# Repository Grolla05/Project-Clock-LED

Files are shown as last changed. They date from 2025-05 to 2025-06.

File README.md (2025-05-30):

# ⏱️ Project Clock LED — Digital Clock with Logic Circuits

> A fully functional digital clock built **without programming**, using only digital logic and discrete electronics.



---

## 🧩 What is DigitalClock?

**DigitalClock** is a project developed with the goal of creating a **complete digital clock** capable of accurately counting hours, minutes, and seconds using **only discrete electronic components and digital logic circuits**, **without any programming languages or microcontrollers**.

The project was designed to practically apply knowledge acquired in **Electronics** and **Digital Circuits** courses, resulting in a system capable of operating continuously and stably, displaying the time in real-time on **seven-segment LED displays**.

---

## 🎯 Project Objectives

- ⚡ Design and implement a **rectifier power supply** with proper filtering to power the digital circuits  
- ⏳ Develop a **clock generation system** using **delay and frequency divider circuits**  
- 🔁 Create **synchronous and asynchronous counters** using D flip-flops to count seconds, minutes, and hours  
- 🔢 Integrate **binary to 7-segment decoders** with the counters to correctly display the time values  

---

## ⚙️ Features

✔️ Accurate time counting (hours, minutes, and seconds)  
✔️ Continuous and stable real-time operation  
✔️ Real-time updates on seven-segment displays  
✔️ Fully built with discrete digital logic components  
✔️ No programming or microcontrollers involved  
✔️ Educational project focused on fundamental electronics

---

## 🛠️ Components and Technologies

- **D-type Flip-Flops**  
- **Synchronous/Asynchronous Counters**
- **Pulse Generator (CLOCK)** 
- **Frequency Dividers**  
- **BCD to 7-Segment Decoders**  
- **7-Segment LED Displays**
- **Diode LED's**
- **Rectifier Power Supply with Filter Capacitors**  
- **Logic Gates (AND, NOT, etc...)**

---

## ✨ System Demonstration

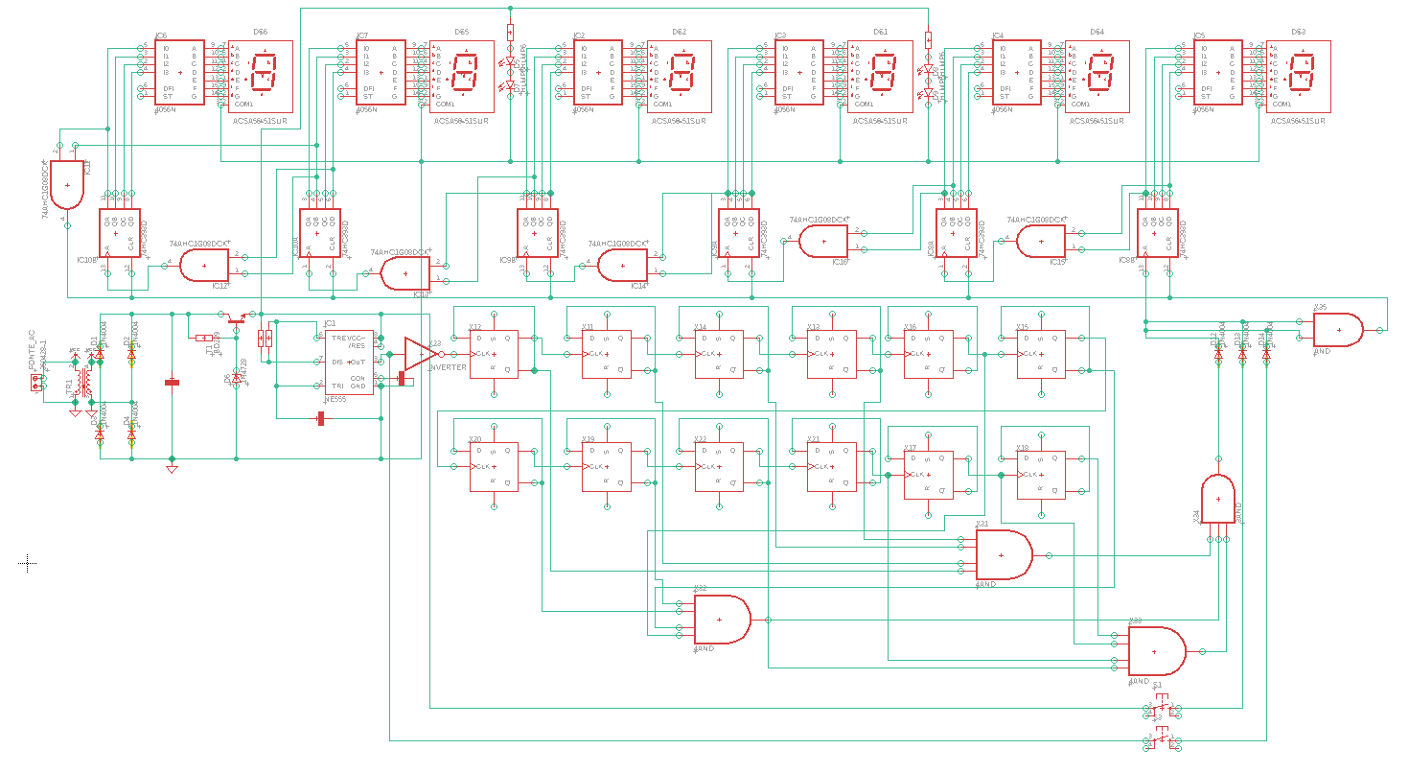
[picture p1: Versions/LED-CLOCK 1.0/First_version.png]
 <br>
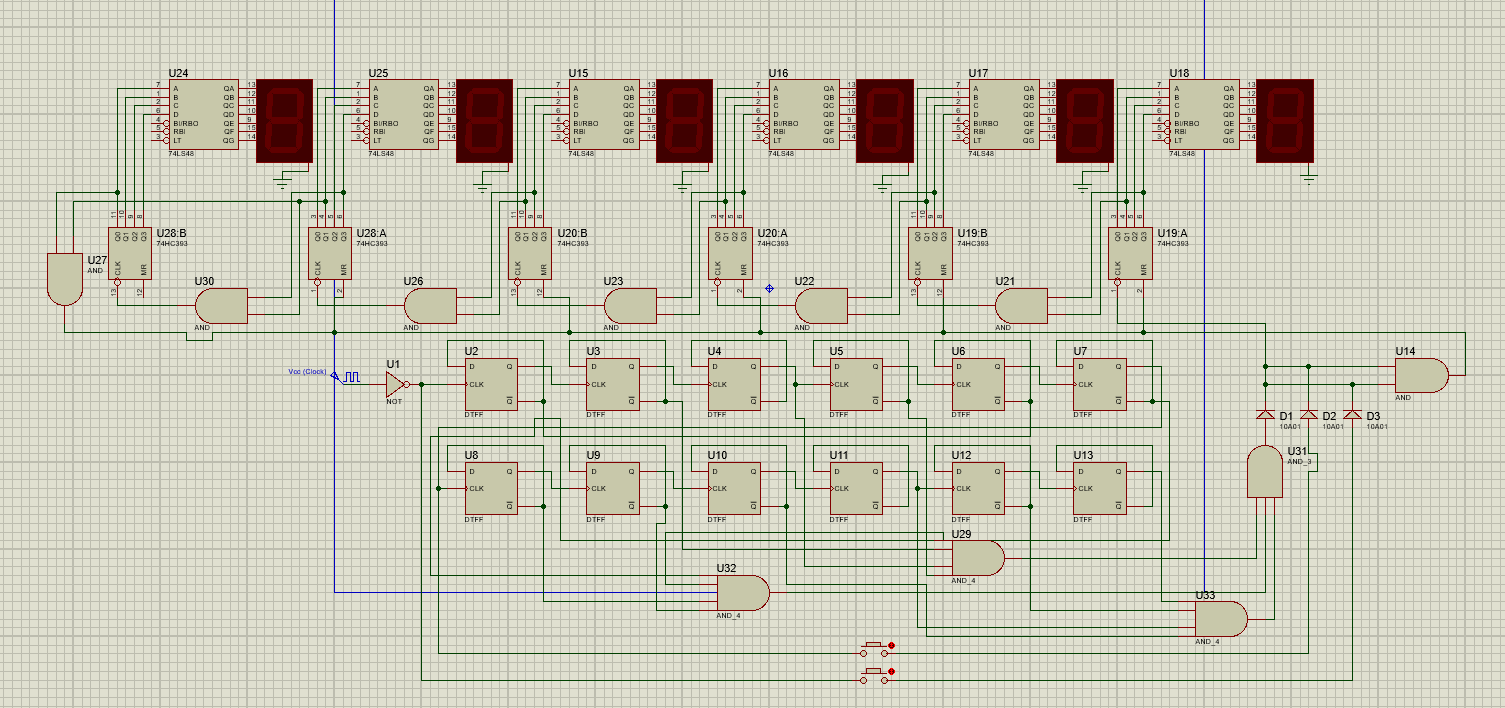
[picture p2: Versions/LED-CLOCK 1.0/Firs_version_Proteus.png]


---

## 👥 Author's

Developed by:

- **Felipe Grolla Freitas** – Control and Automation Engineering Student (PUC-Campinas)
- **Guilherme Oliveira Nogueira** - Control and Automation Engineering Student (PUC-Campinas)
- **Giovanna Lima Salvagnini** - Control and Automation Engineering Student (PUC-Campinas)
- **Henrique Spadaccia Chambó** - Control and Automation Engineering Student (PUC-Campinas)

---

## 💬 Contributions and Learning

This project demonstrated how to build a fully functional digital system using only the fundamentals of sequential and combinational logic.  
It reinforced practical understanding of counters, timing, clock generation, and display interfacing without any programming.

---

> 🧠 *"Digital logic can build time — one pulse at a time."*

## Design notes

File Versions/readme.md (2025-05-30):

# Materials list

- **6 - 7 seg display**
- **6 - decodificador (7 segmentos display)**
- **6 - registradores de 4 bits**
- **4 - leds simples**
- **7 - Portas ands simples**
- **1 - porta and de 3 entradas**
- **3 - porta and de 4 entradas**
- **2 - botões (chave)**
- **12 - flipflops tipo D**
- **1 - porta not**
- **7 - diodos retificadores**
- **1 - oscilador NE555**
- **1 - resistor 1K**
- **1 - transistor NPN BD135**
- **1 - capacitor 220 uF**
- **1 - Zener 1N4728**
- **1 - transformador de 127v para 6v**

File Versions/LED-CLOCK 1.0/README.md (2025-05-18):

## First version of the project (CLOCK LED with only analog and logic circuit)



## First version of the project in proteus



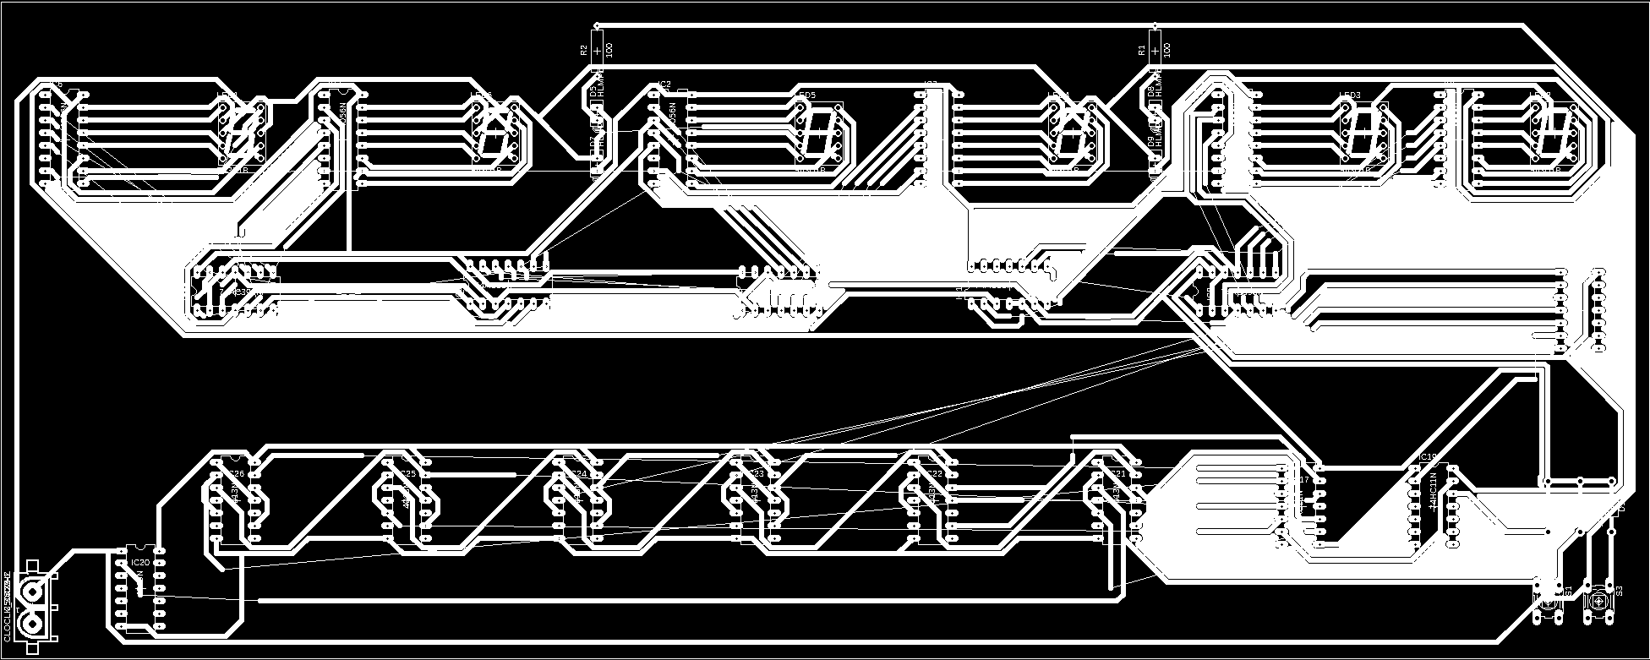
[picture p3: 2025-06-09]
Versions/LED-CLOCK 1.0/Modulo 1/Bottom side 2.png

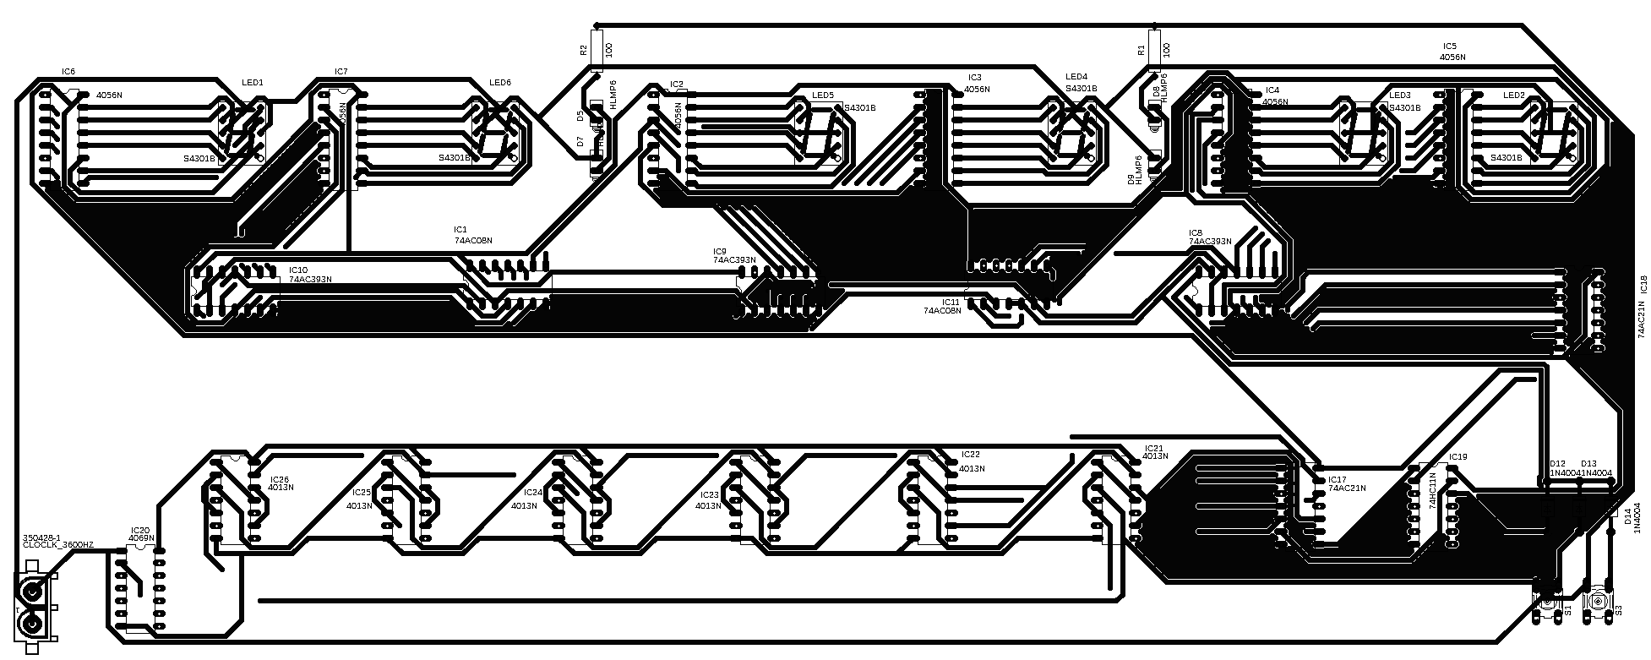
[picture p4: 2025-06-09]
Versions/LED-CLOCK 1.0/Modulo 1/Bottom side.png

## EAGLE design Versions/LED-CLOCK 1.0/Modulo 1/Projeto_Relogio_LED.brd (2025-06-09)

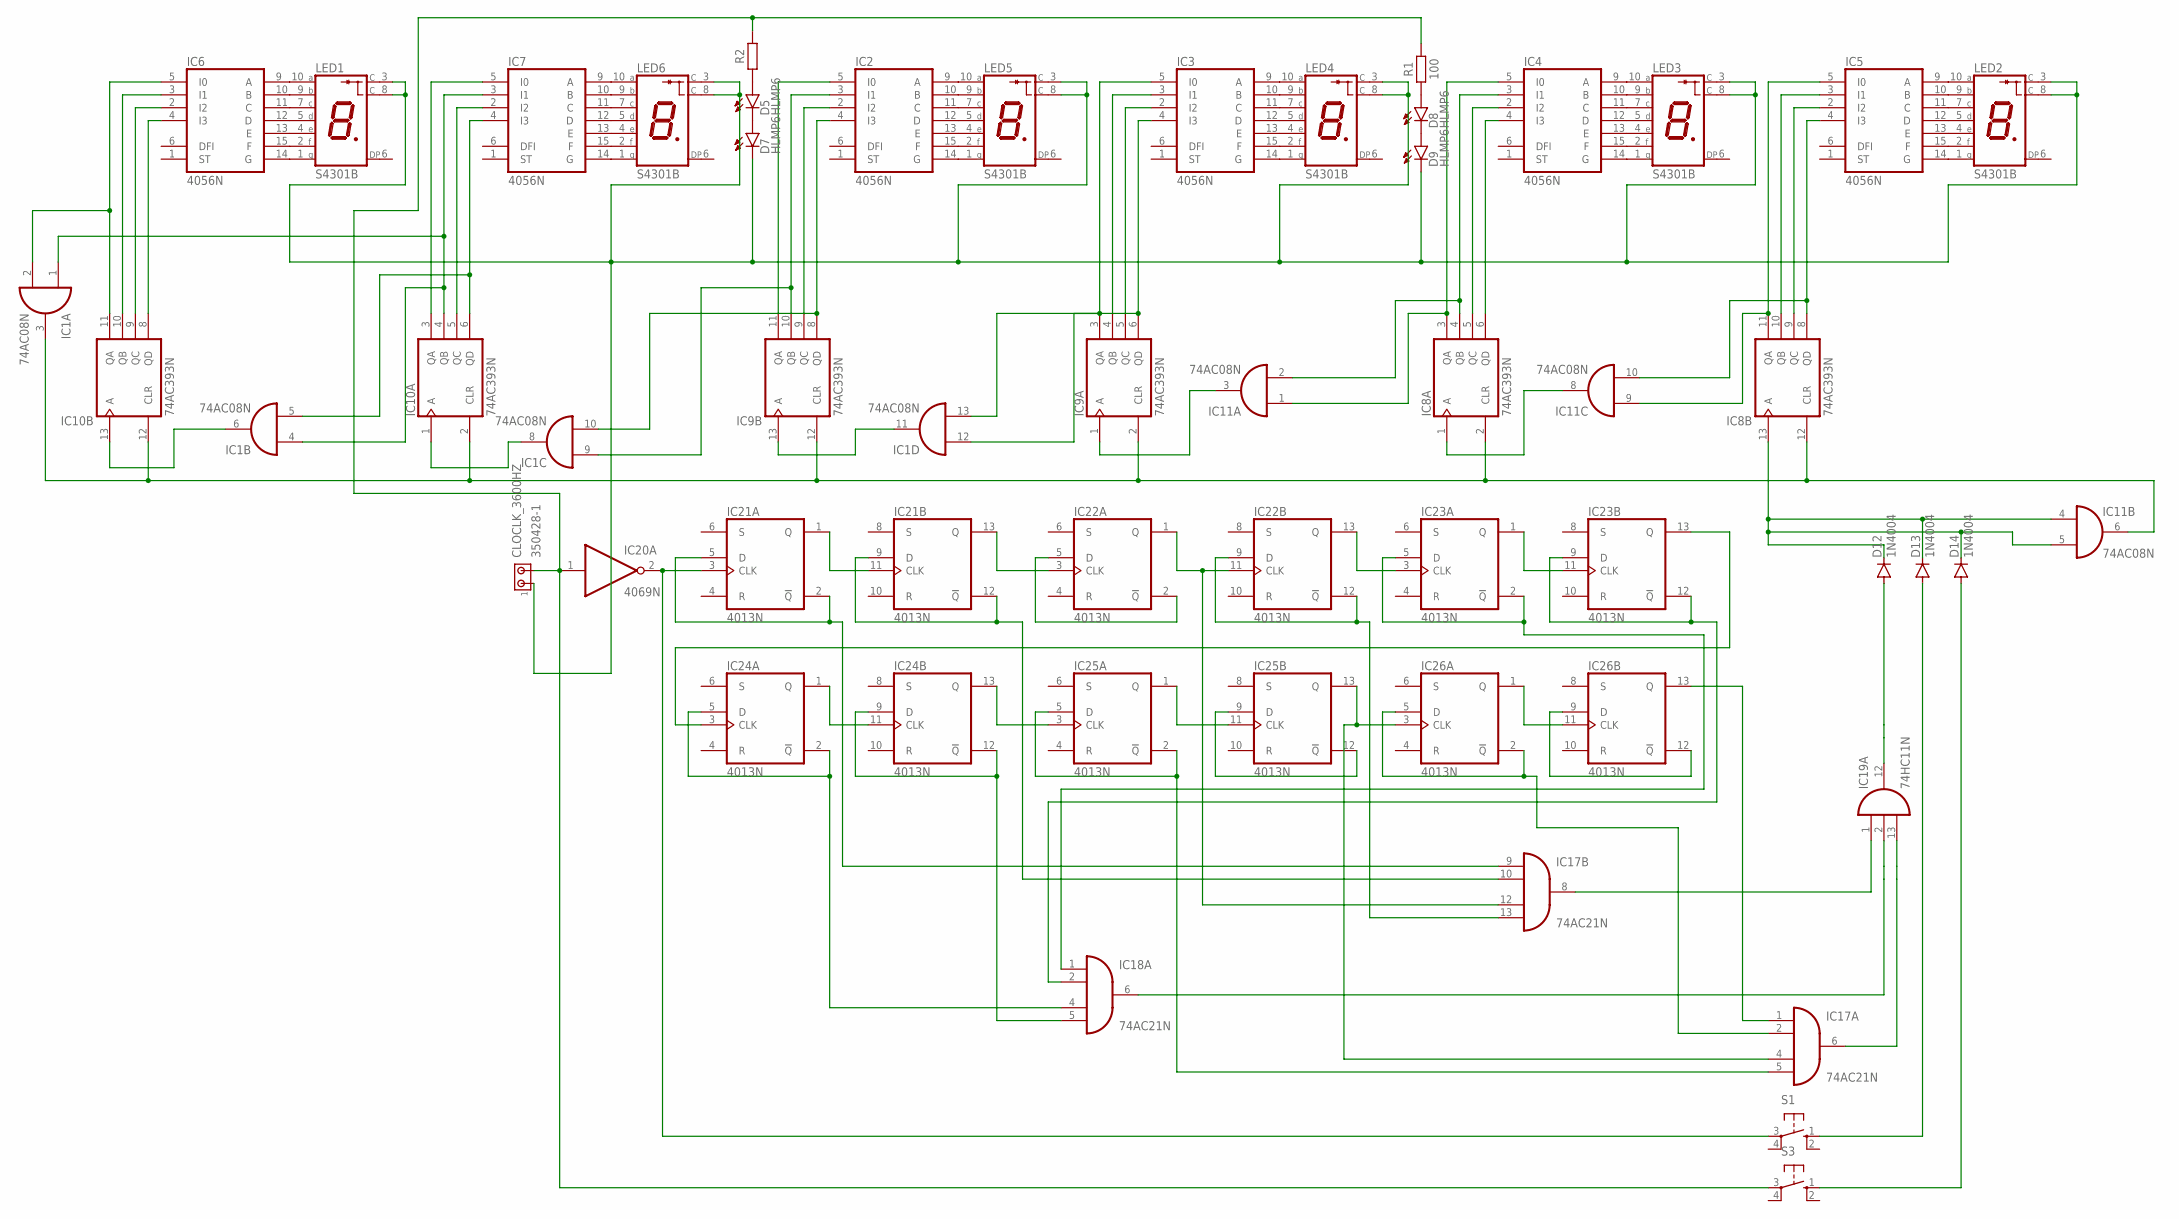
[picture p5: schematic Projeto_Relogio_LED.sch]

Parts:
CLOCLK_3600HZ: 350428-1
D5, D7, D8, D9: HLMP6
D12, D13, D14: 1N4004; DO41-10
IC1, IC11: 74AC08N; DIL14
IC2, IC3, IC4, IC5, IC6, IC7: 4056N; DIL16
IC8, IC9, IC10: 74AC393N; DIL14
IC17, IC18: 74AC21N; DIL14
IC19: 74HC11N; DIL14
IC20: 4069N; DIL14
IC21, IC22, IC23, IC24, IC25, IC26: 4013N; DIL14
LED1, LED2, LED3, LED4, LED5, LED6: S4301B
R1, R2: 100; RESAD1016W63L850D250B
S1, S3: 10-XX; B3F-10XX

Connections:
GND: IC1.7 (GND), IC2.8 (GND), IC3.8 (GND), IC4.8 (GND), IC5.8 (GND), IC6.8 (GND), IC7.8 (GND), IC8.7 (GND), IC9.7 (GND), IC10.7 (GND), IC11.7 (GND), IC17.7 (GND), IC18.7 (GND), IC19.7 (GND)
unnamed: IC1.8 (O), IC10.1 (A)
unnamed: IC5.4 (I3), IC8.8 (QD), IC11.10 (I1)
unnamed: IC8.1 (A), IC11.8 (O)
unnamed: D5.A, R2.1
unnamed: D8.A, R1.1
unnamed: D12.A, IC19.12 (O)
unnamed: IC20.2 (O), IC21.3 (CLK), S1.3
unnamed: IC21.1 (Q), IC21.11 (CLK)
unnamed: CLOCLK_3600HZ.2, IC20.1 (I), R1.2, R2.2, S3.3
unnamed: IC21.13 (Q), IC22.3 (CLK)
unnamed: IC17.12 (I2), IC22.1 (Q), IC22.11 (CLK)
unnamed: IC22.13 (Q), IC23.3 (CLK)
unnamed: IC23.1 (Q), IC23.11 (CLK)
unnamed: IC24.1 (Q), IC24.11 (CLK)
unnamed: IC18.4 (I2), IC24.2 (!Q), IC24.5 (D)
unnamed: IC24.13 (Q), IC25.3 (CLK)
unnamed: IC25.1 (Q), IC25.11 (CLK)
unnamed: IC17.4 (I2), IC25.13 (Q), IC26.3 (CLK)
unnamed: IC26.1 (Q), IC26.11 (CLK)
unnamed: IC23.13 (Q), IC24.3 (CLK)
unnamed: IC7.14 (G), LED6.1 (G)
unnamed: IC7.15 (F), LED6.2 (F)
unnamed: IC7.13 (E), LED6.4 (E)
unnamed: IC7.12 (D), LED6.5 (D)
unnamed: IC7.11 (C), LED6.7 (C)
unnamed: IC7.10 (B), LED6.9 (B)
unnamed: IC7.9 (A), LED6.10 (A)
unnamed: IC6.9 (A), LED1.10 (A)
unnamed: IC6.10 (B), LED1.9 (B)
unnamed: IC6.11 (C), LED1.7 (C)
unnamed: IC6.12 (D), LED1.5 (D)
unnamed: IC6.13 (E), LED1.4 (E)
unnamed: IC6.15 (F), LED1.2 (F)
unnamed: IC6.14 (G), LED1.1 (G)
unnamed: IC2.14 (G), LED5.1 (G)
unnamed: IC2.15 (F), LED5.2 (F)
unnamed: IC2.13 (E), LED5.4 (E)
unnamed: IC2.12 (D), LED5.5 (D)
unnamed: IC2.11 (C), LED5.7 (C)
unnamed: IC2.10 (B), LED5.9 (B)
unnamed: IC2.9 (A), LED5.10 (A)
unnamed: IC3.9 (A), LED4.10 (A)
unnamed: IC3.10 (B), LED4.9 (B)
unnamed: IC3.11 (C), LED4.7 (C)
unnamed: IC3.12 (D), LED4.5 (D)
unnamed: IC3.13 (E), LED4.4 (E)
unnamed: IC3.15 (F), LED4.2 (F)
unnamed: IC3.14 (G), LED4.1 (G)
unnamed: IC4.14 (G), LED3.1 (G)
unnamed: IC4.15 (F), LED3.2 (F)
unnamed: IC4.13 (E), LED3.4 (E)
unnamed: IC4.12 (D), LED3.5 (D)
unnamed: IC4.11 (C), LED3.7 (C)
unnamed: IC4.10 (B), LED3.9 (B)
unnamed: IC4.9 (A), LED3.10 (A)
unnamed: IC5.14 (G), LED2.1 (G)
unnamed: IC5.15 (F), LED2.2 (F)
unnamed: IC5.13 (E), LED2.4 (E)
unnamed: IC5.12 (D), LED2.5 (D)
unnamed: IC5.11 (C), LED2.7 (C)
unnamed: IC5.10 (B), LED2.9 (B)
unnamed: IC5.9 (A), LED2.10 (A)
unnamed: IC4.4 (I3), IC8.6 (QD)
unnamed: IC4.2 (I2), IC8.5 (QC)
unnamed: IC4.3 (I1), IC8.4 (QB), IC11.2 (I1)
unnamed: IC4.5 (I0), IC8.3 (QA), IC11.1 (I0)
unnamed: IC5.2 (I2), IC8.9 (QC)
unnamed: IC5.3 (I1), IC8.10 (QB)
unnamed: IC5.5 (I0), IC8.11 (QA), IC11.9 (I0)
unnamed: IC1.13 (I1), IC3.4 (I3), IC9.6 (QD)
unnamed: IC3.2 (I2), IC9.5 (QC)
unnamed: IC3.3 (I1), IC9.4 (QB)
unnamed: IC1.12 (I0), IC3.5 (I0), IC9.3 (QA)
unnamed: IC1.10 (I1), IC2.4 (I3), IC9.8 (QD)
unnamed: IC2.2 (I2), IC9.9 (QC)
unnamed: IC1.9 (I0), IC2.3 (I1), IC9.10 (QB)
unnamed: IC2.5 (I0), IC9.11 (QA)
unnamed: IC1.5 (I1), IC7.4 (I3), IC10.6 (QD)
unnamed: IC7.2 (I2), IC10.5 (QC)
unnamed: IC1.1 (I0), IC1.4 (I0), IC7.3 (I1), IC10.4 (QB)
unnamed: IC7.5 (I0), IC10.3 (QA)
unnamed: IC6.4 (I3), IC10.8 (QD)
unnamed: IC6.2 (I2), IC10.9 (QC)
unnamed: IC6.3 (I1), IC10.10 (QB)
unnamed: IC1.2 (I1), IC6.5 (I0), IC10.11 (QA)
unnamed: D5.K, D7.A
unnamed: D8.K, D9.A
unnamed: IC17.10 (I1), IC21.9 (D), IC21.12 (!Q)
unnamed: IC22.2 (!Q), IC22.5 (D)
unnamed: IC17.13 (I3), IC22.9 (D), IC22.12 (!Q)
unnamed: IC1.6 (O), IC10.13 (A)
unnamed: IC18.1 (I0), IC23.2 (!Q), IC23.5 (D)
unnamed: IC18.2 (I1), IC23.9 (D), IC23.12 (!Q)
unnamed: IC18.5 (I3), IC24.9 (D), IC24.12 (!Q)
unnamed: IC17.5 (I3), IC25.2 (!Q), IC25.5 (D)
unnamed: IC25.9 (D), IC25.12 (!Q)
unnamed: IC26.9 (D), IC26.12 (!Q)
unnamed: IC17.9 (I0), IC21.2 (!Q), IC21.5 (D)
unnamed: D12.C, D13.C, D14.C, IC8.13 (A), IC11.4 (I0), IC11.5 (I1)
unnamed: IC17.8 (O), IC19.1 (I0)
unnamed: D13.A, S1.1 (S)
unnamed: D14.A, S3.1 (S)
unnamed: IC18.6 (O), IC19.2 (I1)
unnamed: IC1.3 (O), IC8.2 (CLR), IC8.12 (CLR), IC9.2 (CLR), IC9.12 (CLR), IC10.2 (CLR), IC10.12 (CLR), IC11.6 (O)
unnamed: IC17.1 (I0), IC26.13 (Q)
unnamed: CLOCLK_3600HZ.1, D7.K, D9.K, LED1.3 (C), LED1.8 (C), LED2.3 (C), LED2.8 (C), LED3.3 (C), LED3.8 (C), LED4.3 (C), LED4.8 (C), LED5.3 (C), LED5.8 (C), LED6.3 (C), LED6.8 (C)
unnamed: IC9.1 (A), IC11.3 (O)
unnamed: IC17.2 (I1), IC26.2 (!Q), IC26.5 (D)
unnamed: IC1.11 (O), IC9.13 (A)
unnamed: IC17.6 (O), IC19.13 (I2)
VCC: IC1.14 (VCC), IC2.16 (VCC), IC3.16 (VCC), IC4.16 (VCC), IC5.16 (VCC), IC6.16 (VCC), IC7.16 (VCC), IC8.14 (VCC), IC9.14 (VCC), IC10.14 (VCC), IC11.14 (VCC), IC17.14 (VCC), IC18.14 (VCC), IC19.14 (VCC)
VDD: IC20.14 (VDD), IC21.14 (VDD), IC22.14 (VDD), IC23.14 (VDD), IC24.14 (VDD), IC25.14 (VDD), IC26.14 (VDD)
VEE: IC2.7 (VEE), IC3.7 (VEE), IC4.7 (VEE), IC5.7 (VEE), IC6.7 (VEE), IC7.7 (VEE)
VSS: IC20.7 (VSS), IC21.7 (VSS), IC22.7 (VSS), IC23.7 (VSS), IC24.7 (VSS), IC25.7 (VSS), IC26.7 (VSS)

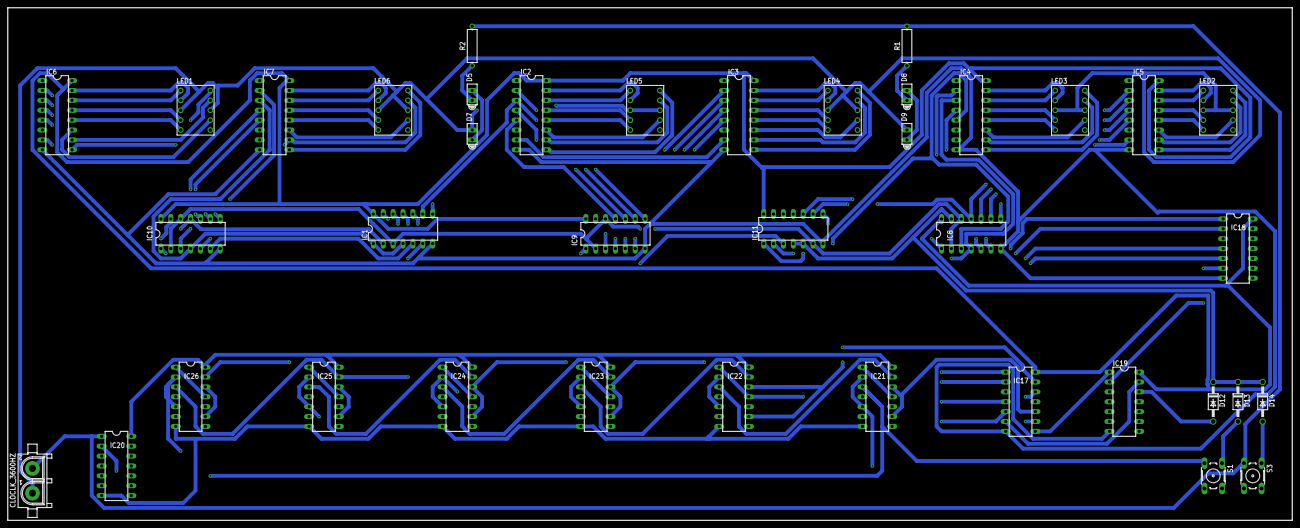
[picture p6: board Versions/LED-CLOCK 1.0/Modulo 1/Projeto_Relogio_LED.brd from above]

Board: 2 copper layers, 330.2 x 131.8 mm, 39 parts (0 on the bottom side), 115 nets.

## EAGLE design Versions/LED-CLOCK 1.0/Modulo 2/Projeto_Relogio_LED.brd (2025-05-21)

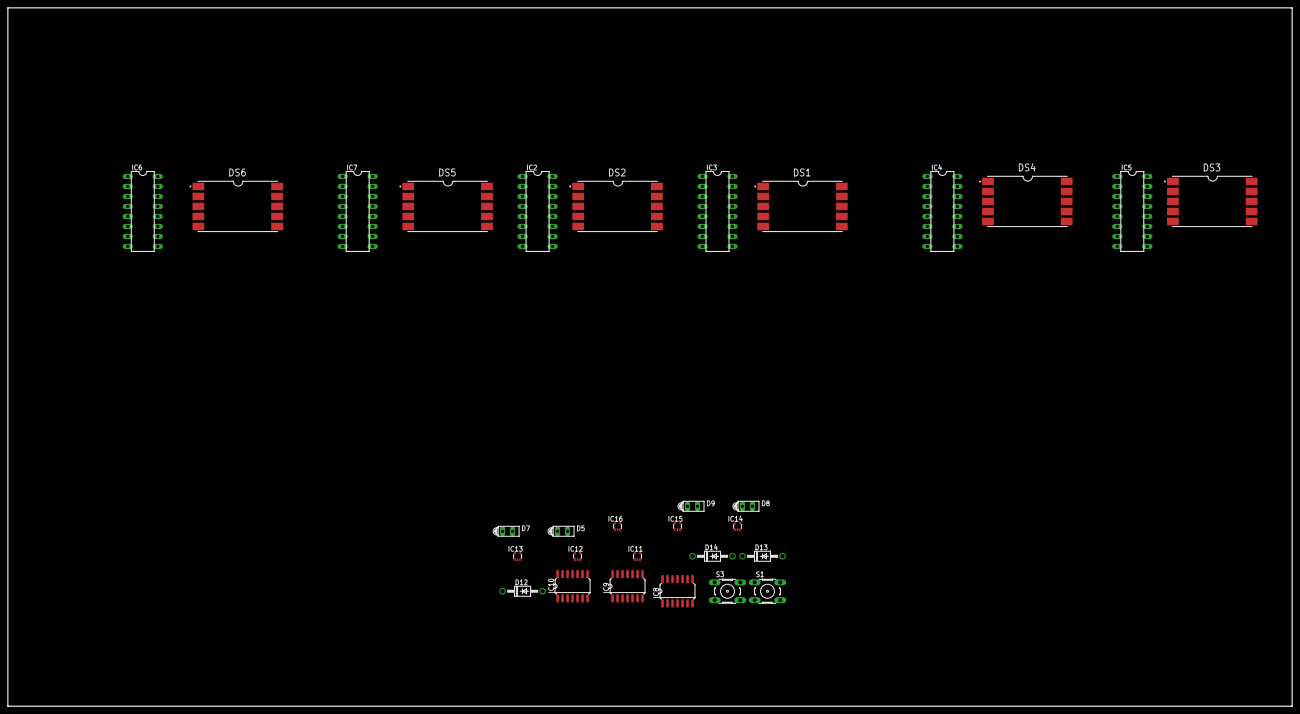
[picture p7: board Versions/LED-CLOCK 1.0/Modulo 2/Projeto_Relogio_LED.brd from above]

Board: 2 copper layers, 326.4 x 177.5 mm, 30 parts (0 on the bottom side), 80 nets, no tracks yet.

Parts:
D5, D7, D8, D9: HLMP6
D12, D13, D14: 1N4004; DO41-10
DS1, DS2, DS3, DS4, DS5, DS6: ACSA56-51SUR; ACSA56-51SURKWA
IC2, IC3, IC4, IC5, IC6, IC7: 4056N; DIL16
IC8, IC9, IC10: 74HC393D; SO14
IC11, IC12, IC13, IC14, IC15, IC16: 74AHC1G08DCK; SC70-5
S1, S3: B3F-10XX

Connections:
GND: D7.K, D9.K, DS1.3, DS1.8, DS2.3, DS2.8, DS3.3, DS3.8, DS4.3, DS4.8, DS5.3, DS5.8, DS6.3, DS6.8, IC2.8, IC3.8, IC4.8, IC5.8, IC6.8, IC7.8, IC8.7, IC9.7, IC10.7, IC11.3, IC12.3, IC13.3, IC14.3, IC15.3, IC16.3
unnamed: IC10.1, IC13.4
unnamed: IC5.4, IC8.8, IC15.2
unnamed: IC8.1, IC15.4
unnamed: DS5.7, IC7.9
unnamed: DS5.6, IC7.10
unnamed: DS5.4, IC7.11
unnamed: DS5.2, IC7.12
unnamed: DS5.1, IC7.13
unnamed: DS5.5, DS5.10, IC7.14
unnamed: DS5.9, IC7.15
unnamed: DS6.7, IC6.9
unnamed: DS6.6, IC6.10
unnamed: DS6.4, IC6.11
unnamed: DS6.2, IC6.12
unnamed: DS6.1, IC6.13
unnamed: DS6.5, DS6.10, IC6.14
unnamed: DS6.9, IC6.15
unnamed: DS3.7, IC5.9
unnamed: DS3.6, IC5.10
unnamed: DS3.4, IC5.11
unnamed: DS3.2, IC5.12
unnamed: DS3.1, IC5.13
unnamed: DS3.5, DS3.10, IC5.14
unnamed: DS3.9, IC5.15
unnamed: DS4.7, IC4.9
unnamed: DS4.6, IC4.10
unnamed: DS4.4, IC4.11
unnamed: DS4.2, IC4.12
unnamed: DS4.1, IC4.13
unnamed: DS4.5, DS4.10, IC4.14
unnamed: DS4.9, IC4.15
unnamed: DS1.7, IC3.9
unnamed: DS1.6, IC3.10
unnamed: DS1.4, IC3.11
unnamed: DS1.2, IC3.12
unnamed: DS1.1, IC3.13
unnamed: DS1.5, DS1.10, IC3.14
unnamed: DS1.9, IC3.15
unnamed: DS2.7, IC2.9
unnamed: DS2.6, IC2.10
unnamed: DS2.4, IC2.11
unnamed: DS2.2, IC2.12
unnamed: DS2.1, IC2.13
unnamed: DS2.5, DS2.10, IC2.14
unnamed: DS2.9, IC2.15
unnamed: IC4.4, IC8.6
unnamed: IC4.2, IC8.5
unnamed: IC4.3, IC8.4, IC16.2
unnamed: IC4.5, IC8.3, IC16.1
unnamed: IC5.2, IC8.9
unnamed: IC5.3, IC8.10
unnamed: IC5.5, IC8.11, IC15.1
unnamed: IC3.4, IC9.6, IC14.2
unnamed: IC3.2, IC9.5
unnamed: IC3.3, IC9.4
unnamed: IC3.5, IC9.3, IC14.1
unnamed: IC2.4, IC9.8, IC13.2
unnamed: IC2.2, IC9.9
unnamed: IC2.3, IC9.10, IC13.1
unnamed: IC2.5, IC9.11
unnamed: IC7.4, IC10.6, IC12.2
unnamed: IC7.2, IC10.5
unnamed: IC7.3, IC10.4, IC11.1, IC12.1
unnamed: IC7.5, IC10.3
unnamed: IC6.4, IC10.8
unnamed: IC6.2, IC10.9
unnamed: IC6.3, IC10.10
unnamed: IC6.5, IC10.11, IC11.2
unnamed: D5.K, D7.A
unnamed: D8.K, D9.A
unnamed: IC10.13, IC12.4
unnamed: D12.C, D13.C, D14.C, IC8.13
unnamed: D13.A, S1.1
unnamed: D14.A, S3.1
unnamed: IC8.2, IC8.12, IC9.2, IC9.12, IC10.2, IC10.12, IC11.4
unnamed: IC9.1, IC16.4
unnamed: IC9.13, IC14.4
VCC: IC2.16, IC3.16, IC4.16, IC5.16, IC6.16, IC7.16, IC8.14, IC9.14, IC10.14, IC11.5, IC12.5, IC13.5, IC14.5, IC15.5, IC16.5
VEE: IC2.7, IC3.7, IC4.7, IC5.7, IC6.7, IC7.7

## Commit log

2025-05-10 Update versao 1.0 do circuito
    [Projeto_Relogio_LED.sch]
2025-05-18 Update docs
    [Projeto_Relogio_LED.brd, Projeto_Relogio_LED.sch]
2025-05-21 docs update
    [Projeto_Relogio_LED.brd, Projeto_Relogio_LED.sch]
2025-05-26 update
    Ultima versão para impressão na placa
    [Projeto_Relogio_LED.brd, Projeto_Relogio_LED.sch]
